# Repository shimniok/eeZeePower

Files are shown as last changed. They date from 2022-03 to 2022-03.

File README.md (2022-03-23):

# eeZeePower

If you're sick of hunting around for a power source for your breadboard projects and want a simple, small, 
and convenient power module, well, I feel you. Here's the solution. After you solder in the pin headers,
plug in a USB mini-B cable, select 3.3V or 5V, it's time to Make while 
your pals are still trying to figure out how to wire that 9V battery to a 7805.

## Features

* Selectable 3.3V / VUSB (5V) output meets your common prototyping needs
* Maximum current of 500mA
* USB Mini-B input because we all have a gazillion of these cables
* Two sets of output pins for stable installation
* Small; only takes up a tiny corner of the breadboard
* 100uF and 0.1uF filtering capacitors on the output
* 10uF and 0.1uF filtering caps on the regulator input
* All SMT components populated
* Just add pin headers

[Buy now on Tindie](https://www.tindie.com/products/bot_thoughts/eezee-power/)

[Documentation](https://github.com/shimniok/eeZeePower/tree/master/documentation)

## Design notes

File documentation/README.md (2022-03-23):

# eeZee Power User Guide

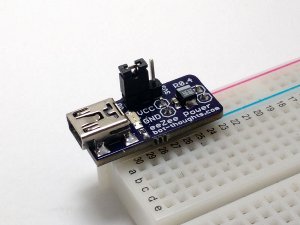
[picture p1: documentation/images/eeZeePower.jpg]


A tiny, affordable breadboard power supply, eeZee Power is powered from common
USB cables that plug into your computer or a phone charger, delivering regulated
3.3V or 5V from the USB connector. If that sounds convenient, then
[buy one on Tindie](https://www.tindie.com/products/bot_thoughts/eezee-power/).

## Getting Started

* Install pin headers
* Place the selector jumper...
  * On the 3V3 side for 3.3V
  * On the VU side for VUSB (~5V)
* Find a mini-B USB cable
* Find a USB phone charger or use your computer
* Plug the cable into the power source and eeZee Power
* Align VCC/GND to the power rails on your breadboard
* Insert eeZee Power into the breadboard

## How to Assemble

Assembly is easy. And, you can learn how to solder at the same time. Review [Sparkfun's Soldering Tutorial](https://learn.sparkfun.com/tutorials/how-to-solder---through-hole-soldering) if you need to. Here's a helpful info-graphic from the tutorial:

soldering infographic

### You'll need
* Soldering iron, 40W
* Sponge to clean the iron (I recommend a brass sponge)
* Workbench with plenty of light
* Ventilation since breathing flux fumes is irritating
* Soldering surface (e.g., marble tile sample)
* Rosin core solder 0.022” or 0.032” diameter
* Kester #2331-ZX flux pen (optional)

### Power pins
Start by placing a pair of 2-pin headers in a breadboard, spaced 0.4” apart
(two holes between).

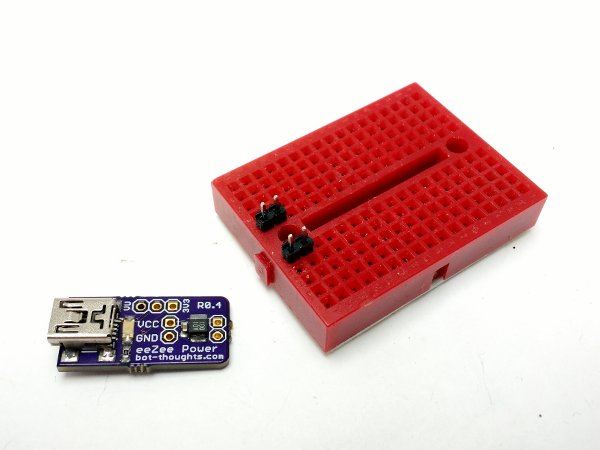
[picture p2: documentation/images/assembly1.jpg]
assembly1


Place the eeZeePower board onto the pin headers, with USB connector on top

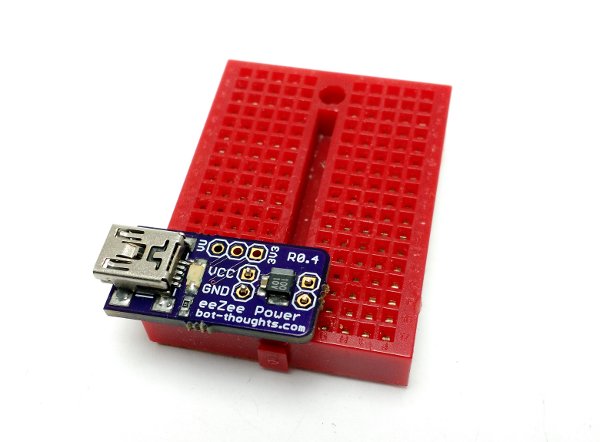
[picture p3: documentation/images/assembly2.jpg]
assembly2


Hold eeZeePower in place and solder on the two sets of headers.

### Selector pins

Now, install the 3-pin header on the top (USB connector side) of the VU/3V3
pads.

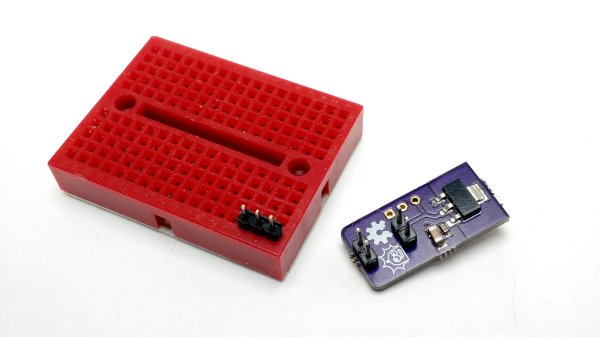
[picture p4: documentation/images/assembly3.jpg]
assembly3


This is kind of tricky, because there's no good way to hold it in place and you
have to be careful that you don't burn your fingers while holding the 3-pin
header.

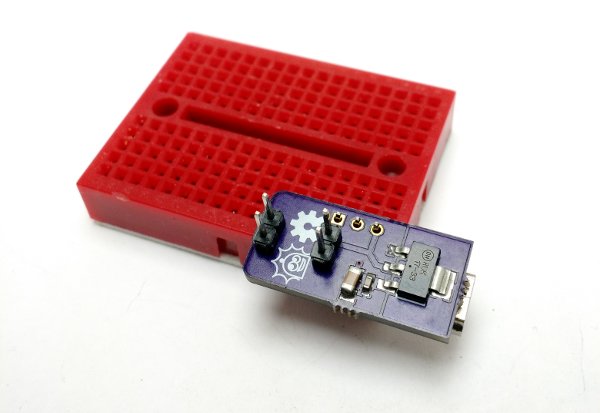
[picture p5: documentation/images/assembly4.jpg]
assembly4


I usually tack one of the outer pins in place with the board upside down.

The result is a crooked pin header. I then carefully apply pressure to an
unsoldered pin while re-melting the soldered pin, and nudge the pin header to
a vertical position.

### Cleanup

You'll want to remove the rosin and flux

I usually just use isopropyl alcohol and an old toothbrush

You can also buy chemicals specifically for removing flux and rosin

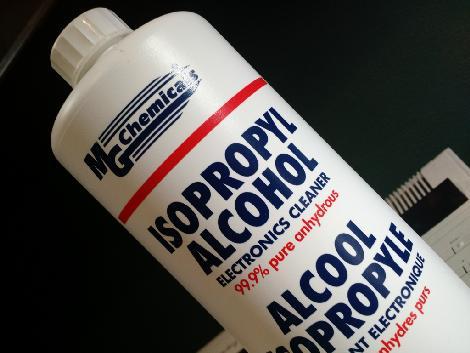
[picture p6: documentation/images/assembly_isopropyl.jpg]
insert pin headers


## How to use

eeZee Power is designed to be installed into the power rails on a typical
solderless breadboard.

For 3.3V operation, install the jumper across the 3V3 and center pins of the
3-pin header.

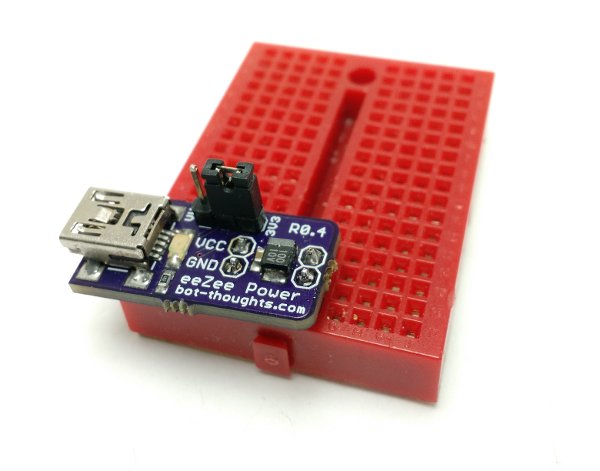
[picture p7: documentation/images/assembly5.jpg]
assembly5


To power directly from the USB connector's VUSB pin (typically ~5V), place the
jumper across the VU and center pins of the 3-pin header.

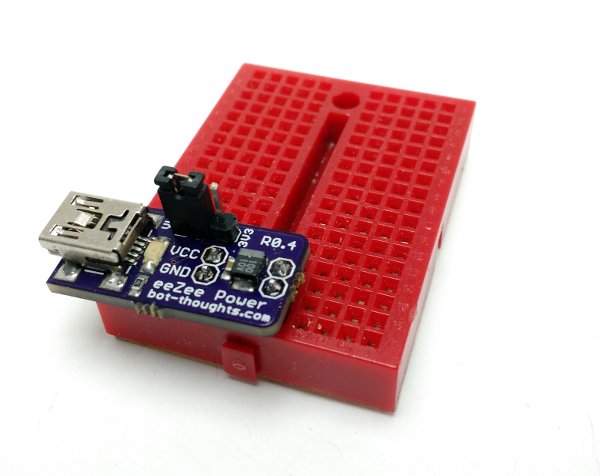
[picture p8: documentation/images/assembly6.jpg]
assembly6


## Specifications

Changes to Rev 0.5 vs. Rev 0.4:

  * All capacitors are rated 25V or higher
  * Integrated two-layer copper heatsinks with thermal vias

Changes to Rev 0.4 vs. Rev 0.5:

  * Vin MAX = 6V
  * All capacitors rated 10V or higher

Rev 0.3 or older:

  * Vin MAX = 5V, **do not exceed**
  * Vin MIN = 3.3V + 1.2V
  * All capacitors are rated 6.3V or higher
  * PCB features an integrated 1cm<sup>2</sup> copper heatsink.
  * Output current for regulated 3.3V: see *3.3V Regulator*
    * If exceeding 500mA, **monitor board temperature**

All eeZee Powers use one of the following 3.3V SOT-223 regulators:

  * ST Micro LD1117S33TR
    * rated at 800mA, max
    * current and thermal limit
    * Datasheet: [LD1117.pdf](http://www.st.com/web/en/resource/technical/document/datasheet/CD00000544.pdf)
  * On Semi NCP1117ST33T3G in SOT-223
    * rated at 1A, max
    * current limit, safe operating and thermal shutdown protection.
    * Datasheet: [NCP1117ST33T3G.pdf](http://datasheet.octopart.com/NCP1117ST33T3G-ON-Semiconductor-datasheet-11536806.pdf)

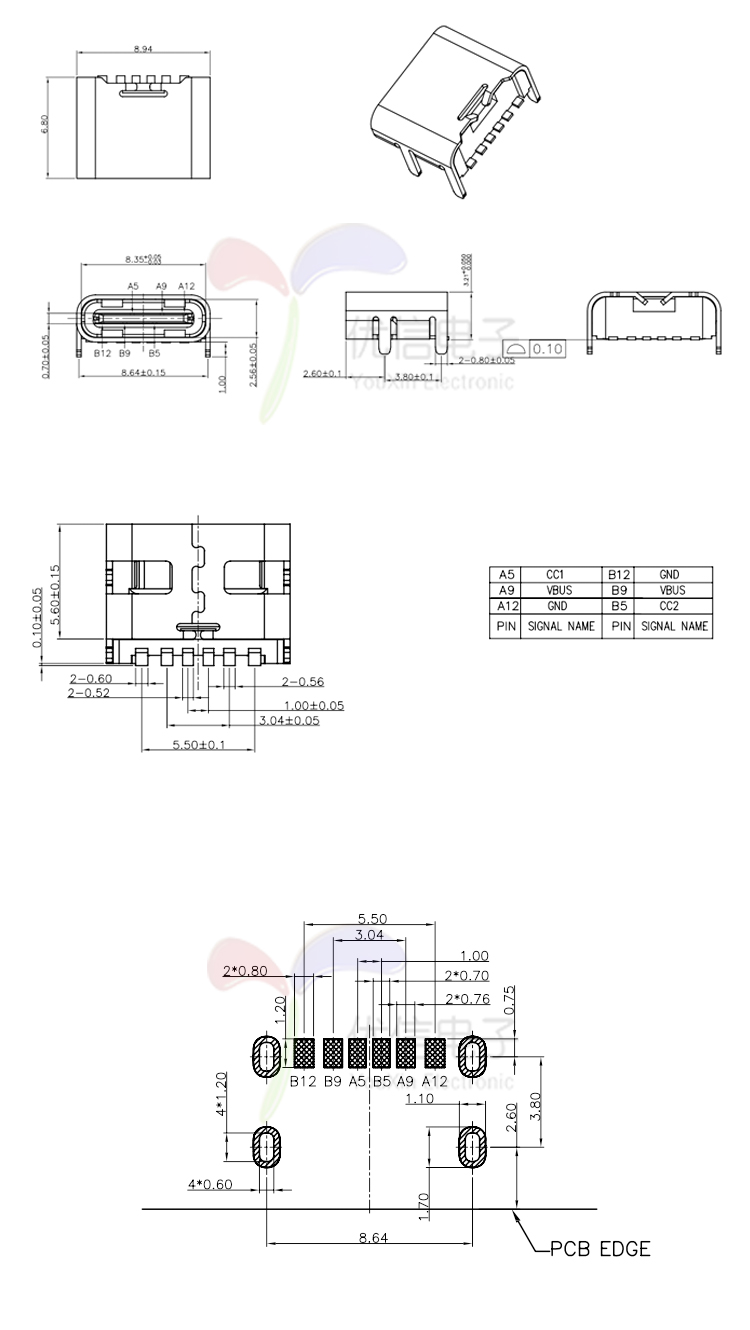
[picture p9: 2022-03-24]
electronics/c/microusb_c.jpg

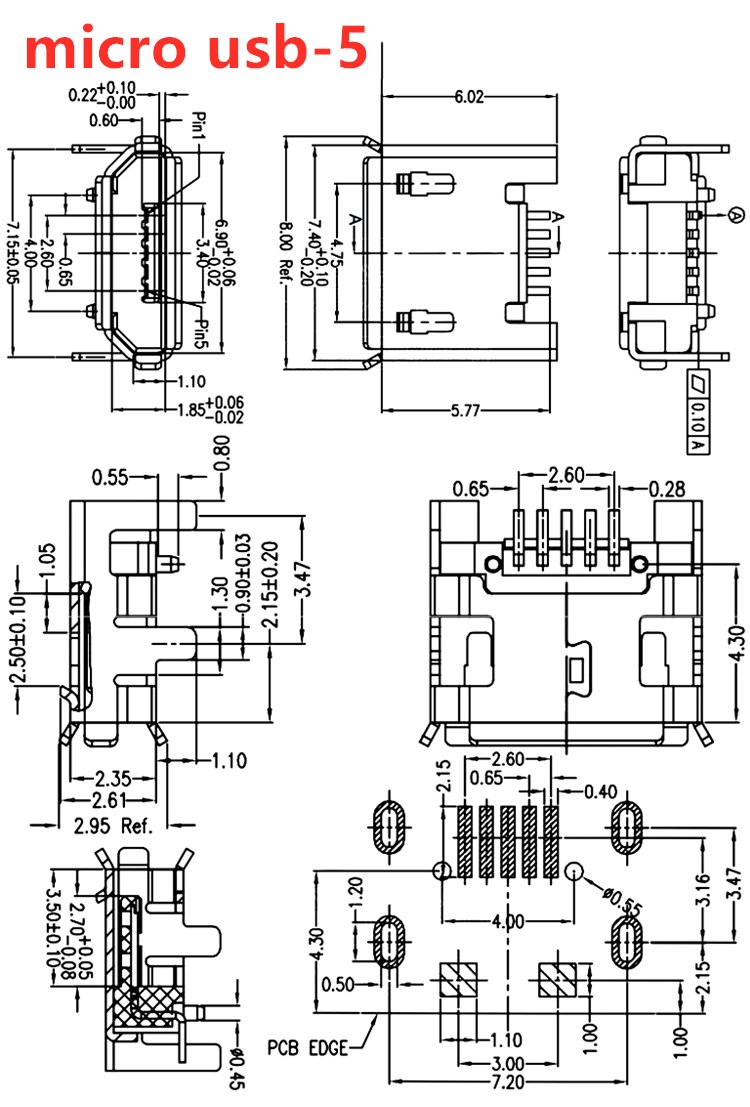
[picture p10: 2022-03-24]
electronics/micro/microusb5.jpg

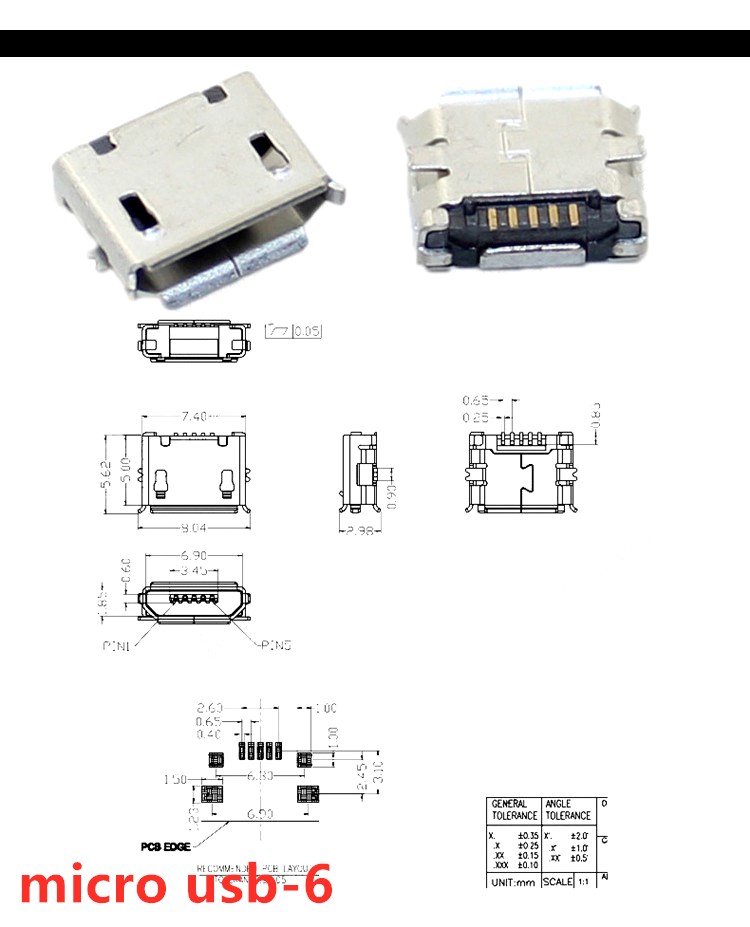
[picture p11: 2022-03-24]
electronics/micro/microusb6.jpg

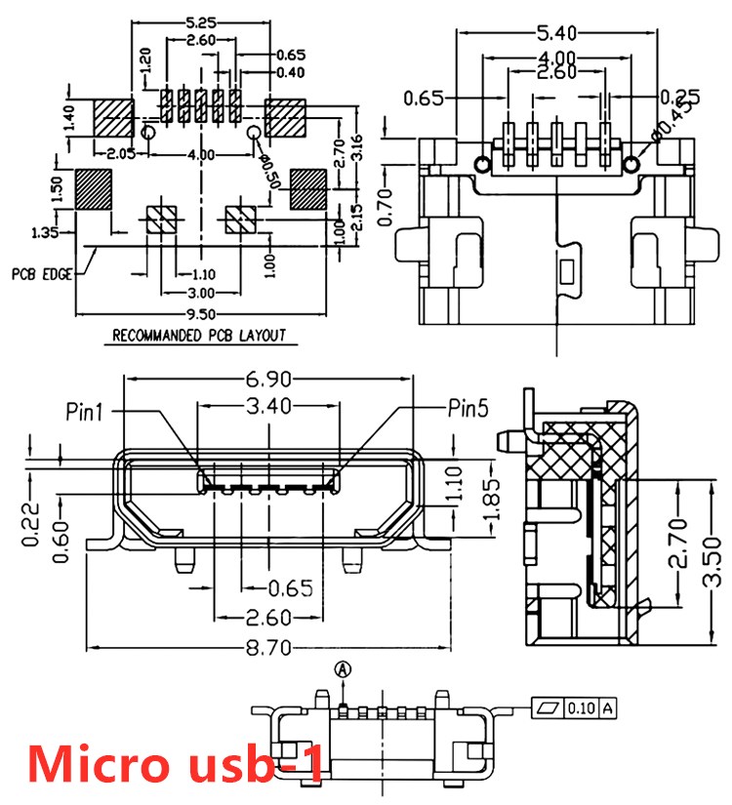
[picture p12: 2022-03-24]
electronics/micro/microusb1.jpg

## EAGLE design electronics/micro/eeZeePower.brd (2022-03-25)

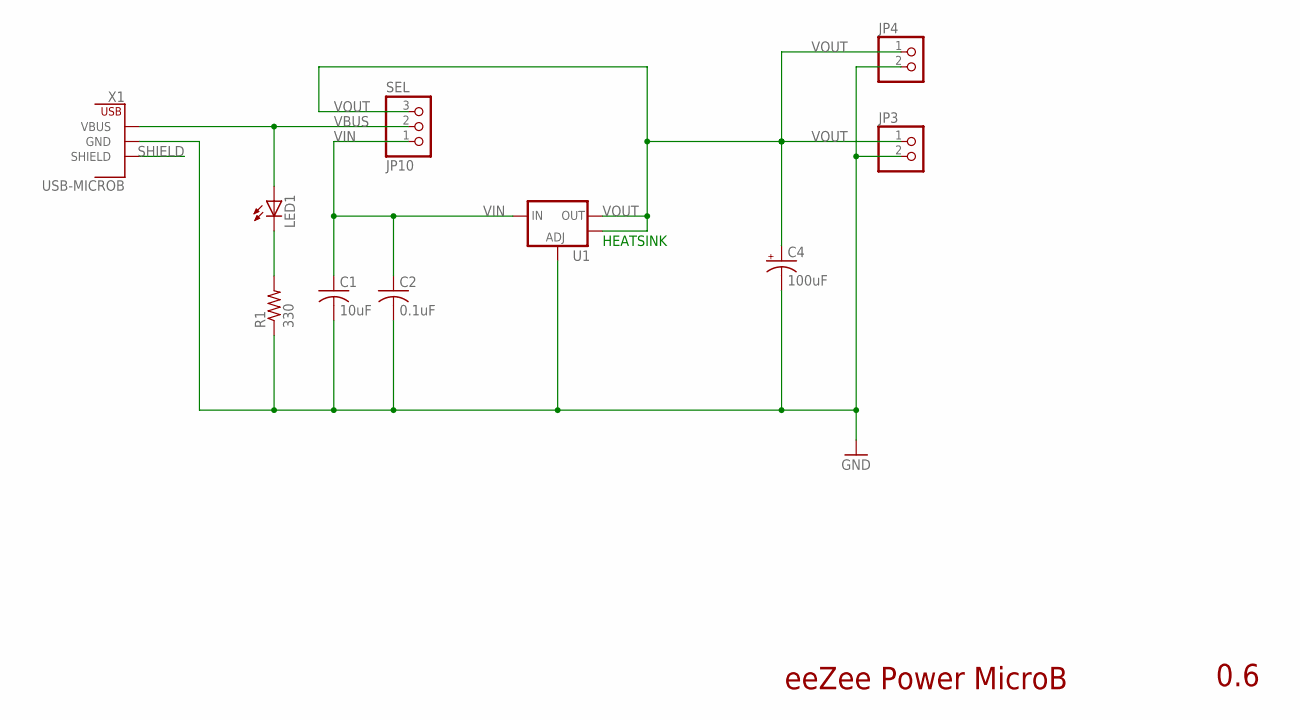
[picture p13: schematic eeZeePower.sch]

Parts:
C1: 10uF; C1206
C2: 0.1uF; C0603
C4: 100uF; SMC_B
JP3, JP4: PINHD-1X02_2.54-S; 1X02-S
JP10: SEL; 1X03-S
LED1: LEDCHIPLED_1206; CHIPLED_1206
R1: 330; R0603
U1: V_REG_LM1117SOT223; SOT223
X1: USB-MICROB; USB-MICROB-4

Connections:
GND: C1.2, C2.2, C4.-, JP3.2, JP4.2, R1.1, U1.1 (ADJ), X1.GND
unnamed: LED1.C, R1.2
SHIELD: X1.SHIELD1 (SHIELD), X1.SHIELD2 (SHIELD), X1.SHIELD3 (SHIELD), X1.SHIELD4 (SHIELD), X1.SHIELD5 (SHIELD), X1.SHIELD6 (SHIELD)
VBUS: JP10.2, LED1.A, X1.VBUS
VIN: C1.1, C2.1, JP10.1, U1.3 (IN)
VOUT: C4.+, JP3.1, JP4.1, JP10.3, U1.2 (OUT), U1.4 (OUT)

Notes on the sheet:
eeZee Power MicroB
0.6
HEATSINK

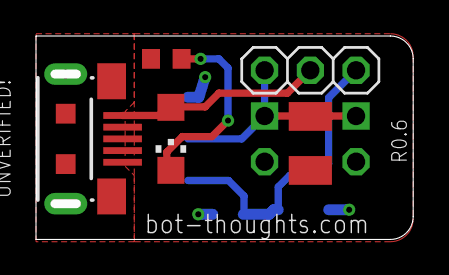
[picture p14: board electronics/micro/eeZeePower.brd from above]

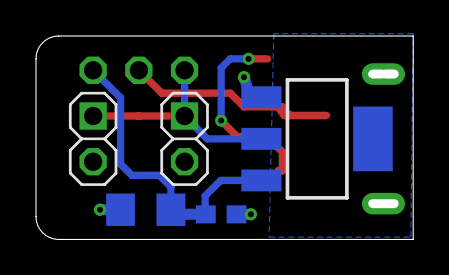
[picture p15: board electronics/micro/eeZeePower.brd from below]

Board: 2 copper layers, 21.0 x 11.3 mm, 10 parts (5 on the bottom side), 6 nets.

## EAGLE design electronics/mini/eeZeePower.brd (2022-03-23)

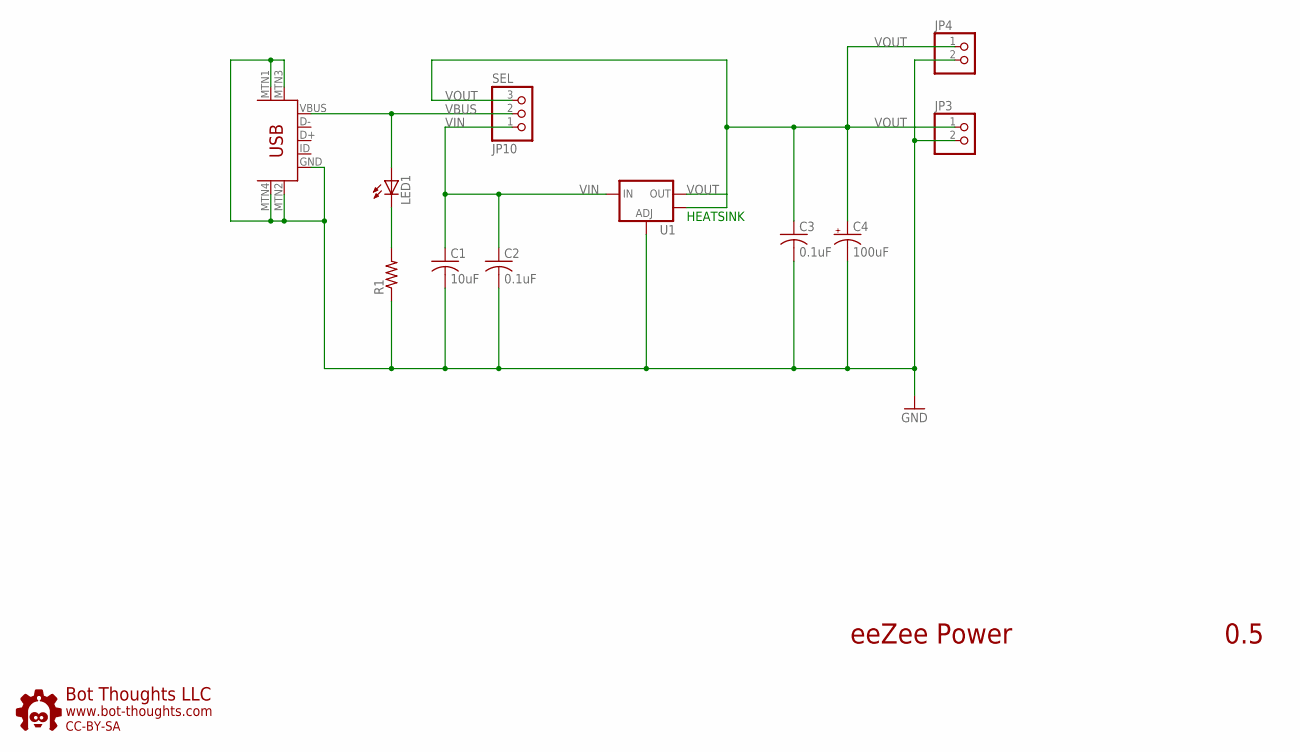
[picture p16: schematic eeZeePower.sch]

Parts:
C1: 10uF; C1206
C2, C3: 0.1uF; C0603
C4: 100uF; SMC_B
JP3, JP4: PINHD-1X02_2.54-S; 1X02-S
JP10: SEL; 1X03-S
LED1: LEDCHIPLED_1206; CHIPLED_1206
R1: R-US_R0603; R0603
U1: V_REG_LM1117SOT223; SOT223
U$1: USB-MINIB-5PIN; USB-MINIB
U$2: BTLOGO-LOGO-MD; BTLOGOM

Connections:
GND: C1.2, C2.2, C3.2, C4.-, JP3.2, JP4.2, R1.1, U1.1 (ADJ), U$1.GND, U$1.MTN1 (MTN2), U$1.MTN2 (MTN3), U$1.MTN3 (MTN1), U$1.MTN4
unnamed: LED1.C, R1.2
VBUS: JP10.2, LED1.A, U$1.VBUS
VIN: C1.1, C2.1, JP10.1, U1.3 (IN)
VOUT: C3.1, C4.+, JP3.1, JP4.1, JP10.3, U1.2 (OUT), U1.4 (OUT)

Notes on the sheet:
eeZee Power
0.5
HEATSINK

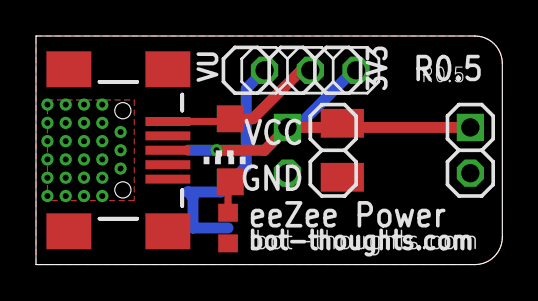
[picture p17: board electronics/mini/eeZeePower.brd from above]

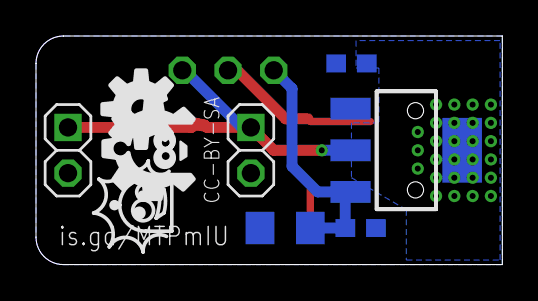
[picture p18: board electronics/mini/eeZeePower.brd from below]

Board: 2 copper layers, 25.9 x 12.7 mm, 12 parts (7 on the bottom side), 5 nets.

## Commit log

2013-01-08 Initial revision
    [eeZeePower.brd, eeZeePower.sch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]
2022-03-23 Fix labels for voltage select jumper
    [eeZeePower.brd, eeZeePower.sch]
2022-03-23 Change LED to standard 1206, centered and moved components, mitered corners, removed component names.
    [eeZeePower.brd, eeZeePower.sch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]
2022-03-23 Converted to standard 1206 10uF, placed input bypass caps on bottom. Rearranged silk, centered pin headers.
    [eeZeePower.brd, eeZeePower.sch]
2022-03-23 Revised silk, updated gerbers
    [eeZeePower.brd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]
2022-03-23 Changed to 10mil/8mil spacing, improved thermal design, connected heatsink to VOUT.
    [eeZeePower.brd, eeZeePower.sch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]
2022-03-23 Updated version # in schematic
    [eeZeePower.sch]
2022-03-23 added assembly guide
2022-03-23 moved electronics into subdirectory
    [eeZeePower.brd, eeZeePower.sch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]
2022-03-23 Changed permissions on electronics files
    [eeZeePower.brd, eeZeePower.sch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]
2022-03-23 initial USB micro-B version
    [eeZeePower.brd, eeZeePower.sch]
2022-03-23 updated microb gerbers
    [eeZeePower.drills.xln]
2022-03-23 added mu-B indicator on silk
    [eeZeePower.brd]
2022-03-23 updated microb with new four-pad library version, added shielding to ground, fixed missing junction
    [eeZeePower.brd, eeZeePower.sch]
2022-03-23 microb: added value to LED resistor, removed silk value
    [eeZeePower.brd, eeZeePower.sch]
2022-03-23 microb: moved silkscreen
    [eeZeePower.brd]
2022-03-23 updated microb after fixing silk in package
    [eeZeePower.brd, eeZeePower.sch]
2022-03-23 microb: Updated version to 0.6
    [eeZeePower.brd, eeZeePower.sch]
2022-03-23 microb: updated silk, updated board name to micro b in schematic
    [eeZeePower.brd, eeZeePower.sch]
2022-03-23 microb: updated zip, gerbers
    [eeZeePower.drills.xln]
2022-03-23 minib: replaced logo; moved power select headers, passives; added help url; updated gerbers, zip
    [eeZeePower.brd, eeZeePower.sch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]
2022-03-23 minib: updated gerbers, zip
    [eeZeePower.drills.xln]
2022-03-23 moved minib files into mini folder
    [eeZeePower.brd, eeZeePower.sch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]
2022-03-23 usbc initial version
    [eeZeePower.brd, eeZeePower.sch]
2022-03-24 c: added help url to board, silk layout tweaks
    [eeZeePower.brd]
2022-03-24 added drawings for micro usb connectors
2022-03-24 added drawing for usb c connector
2022-03-25 microb: replaced usb micro b connector symbol & footprint
    [eeZeePower.brd, eeZeePower.sch]
2022-03-25 layout tweak, shrink board width, fix gnd pour connection
    [eeZeePower.brd, eeZeePower.sch]

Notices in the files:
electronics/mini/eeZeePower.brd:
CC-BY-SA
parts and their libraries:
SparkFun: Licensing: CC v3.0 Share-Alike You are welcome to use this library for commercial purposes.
